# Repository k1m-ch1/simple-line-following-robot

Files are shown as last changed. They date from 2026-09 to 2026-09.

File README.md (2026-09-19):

So we want our angle at which the ir sensor still detect the line to be around 45 to 60 degrees.

So if the distance from the furthest sensor to the middle is $x$, and the distance between the "axel line" and the sensor itself is $r$, then:

$$
\tan \theta = \frac{x}{r}
$$

So, if we actual heading in PID (not very accurate, but I think it's a good mapping):

$$
\theta = \arctan {\frac{x}{r}}
$$

In our case:

- $x \approx 27.5mm$

For $\theta = 60$:

$$
r = \frac{x}{\tan\theta} = \frac{27.5}{\tan 60} = 15.9mm
$$

For $\theta = 30$ meanwhile:

$$
r = 47.63mm
$$

# Microcontroller

I'll try to use the stm32 blue pill for this project because it's high in abundance in terms of I/O. The downside though is that it requires an st-link, and uploading requires like messing around with the jumpers.

I'll see whether using platform io will make this process a bit easier.

Pins:

```
PA0  ADC1_IN0
PA1  ADC1_IN1
PA2  ADC1_IN2
PA3  ADC1_IN3

PA4  ADC1_IN4
PA5  ADC1_IN5
PA6  ADC1_IN6
PA7  ADC1_IN7

PB0  ADC1_IN8
PB1  ADC1_IN9

PC0  ADC1_IN10
PC1  ADC1_IN11
PC2  ADC1_IN12
PC3  ADC1_IN13
PC4  ADC1_IN14
PC5  ADC1_IN15
```

So these all support ADC, meaning that we can have like 2 of these 8 way line sensors!

Anyway, in the platformio world, we can just use `analogRead` for ADC. It's just that it's going to be 12 bits now, which is pretty neat.

## UART

So on the board, A is going to refer to PORT A probably.

### UART 1

```
PA9  → TX
PA10 → RX
```

### UART 2

```
PA2 → TX
PA3 → RX
```

### UART 3

```
PB10 → TX
PB11 → RX
```

## SPI

### SPI 1

```
PA5 → SCK
PA6 → MISO
PA7 → MOSI
```

### SPI 2

```
PB13 → SCK
PB14 → MISO
PB15 → MOSI
```

## I2C

```
PB6 → SCL
PB7 → SDA
```

# Safe GPIO

Safe:

```
PA0–PA7
PB0–PB1
PB5–PB9
PC0–PC15
```

Don't use:

```
PA13 → SWDIO
PA14 → SWCLK
```

## Interrupts

External interrupts are defined like this:

| EXTI line  | Possible GPIO pins |
| --- | --- |
| **EXTI0**  | PA0, PB0, PC0, ... |
| **EXTI1**  | PA1, PB1, PC1, ... |
| **EXTI2**  | PA2, PB2, PC2, ... |
| **EXTI3**  | PA3, PB3, PC3, ... |
| **EXTI4**  | PA4, PB4, PC4, ... |
| **EXTI5**  | PA5, PB5, PC5, ... |
| **EXTI6**  | PA6, PB6, PC6, ... |
| **EXTI7**  | PA7, PB7, PC7, ... |
| **EXTI8**  | PA8, PB8, PC8, ... |
| **EXTI9**  | PA9, PB9, PC9, ... |
| **EXTI10** | PA10, PB10, PC10, ... |
| **EXTI11** | PA11, PB11, PC11, ... |
| **EXTI12** | PA12, PB12, PC12, ... |
| **EXTI13** | PA13, PB13, PC13, ... |
| **EXTI14** | PA14, PB14, PC14, ... |
| **EXTI15** | PA15, PB15, PC15, ... |

So basically, if PA0 uses external interrupts, then PB0, PC0,.. can't use it.

## PWM and bluepill max resolution

Seems like: `16-bit` has a max frequency of `1098.6 Hz`, so the frequency is definitely high enough Servos and even motor control (Arduino's `analogWrite` is also around 1KHz, or even less than that).

Maximum resolution is:

```
b = \log_2 (\frac{f_{timer}}{f_pwm}})
```

For DC motors, I guess a resolution of 10 bits at 20000 Hz should be fine.

## Timers

Timers are grouped as such:

| Timer | Channels | Typical pins |
| --- | --- | --- |
| **TIM1** | CH1–CH4  | PA8, PA9, PA10, PA11 |
| **TIM2** | CH1–CH4  | PA0, PA1, PA2, PA3 |
| **TIM3** | CH1–CH4  | PA6, PA7, PB0, PB1 |
| **TIM4** | CH1–CH4  | PB6, PB7, PB8, PB9 |

timers should also be mapped as such:

| Pin | Possible timer channel |
| --- | --- |
| PA0 | TIM2_CH1 |
| PA1 | TIM2_CH2 |
| PA2 | TIM2_CH3 |
| PA3 | TIM2_CH4 |
| PA6 | TIM3_CH1 |
| PA7 | TIM3_CH2 |
| PB0 | TIM3_CH3 |
| PB1 | TIM3_CH4 |
| PB6 | TIM4_CH1 |
| PB7 | TIM4_CH2 |
| PB8 | TIM4_CH3 |
| PB9 | TIM4_CH4 |

So this code works:

```c
#include <Arduino.h>

#define FREQ_SERVO 50
#define DUTY_CYCLE_SERVO 0.5f

#define FREQ_MOTOR 20000
#define DUTY_CYCLE_MOTOR 0.5f

#define SERVO_PIN PA0

#define MOTOR_PIN PB7

// PB7 | TIM4_CH2               |

HardwareTimer timerServo(TIM2);
HardwareTimer timerMotor(TIM4);

void setup() {
  timerServo.setPWM(1,                     // TIM2 channel 1
                    SERVO_PIN,             // pin
                    FREQ_SERVO,            // frequency
                    DUTY_CYCLE_SERVO * 100 // duty %
  );
  timerServo.resume();

  timerMotor.setPWM(2, MOTOR_PIN, FREQ_MOTOR, DUTY_CYCLE_MOTOR * 100);

  timerMotor.resume();
}

void loop() {}
```

# Servo control

We're not using servos, but it would be nice to know how you would control it very precisely.

First of all, we have angle $\alpha$, then we have the frequency $f$. We want the "ON" pulse to be in the range between $t_{min}$ to $t_{max}$ for the full range.

So essentially, our time period $T$ is going to be $T = \frac{1}{f}$. Then our duty cyle $d = \frac{t}{T}$. Finally, if our angle is 0 to 180, we map it as such:

$$
d = \frac{t_{min} + alpha * \frac{t_{max} - t_{min}}{180}}
$$

Or a another interpretation is a linear blend:

$$
d = f * ((1 - \frac{alpha}{180})t_{min} + \frac{\alpha}{180}t_{max})
$$

We choose $t_{min} = 0.5 ms$ and $t_{max} = 2.5 ms$ for the full range.

So basically, we're blending between $0.5 \times 10^{-3} \times 50 = 0.025$ and $1.5 \times 10^{-3} \times 50 = 0.125$ in terms of duty cycle.

# Timers

So the issue with using the `HardwareTimer` API is that it does have some mechanisms for specifying the PWM signal using parameters such as frequency and duty cycle. The issue is that it rounds off our duty cycle parameter to the nearest integer percentage, which isn't good.

So what we're going to do is reinvent some sort of wheel, and build a PWM abstraction layer similar to the ledc hardware on the ESP32 chip, although we won't manually specify the PWM's resolution, rather, given a duty cycle, we will maximize our resolution every time.

I'll just write it in `pwm.h`, and i'll just call it `pwmAttach` to configure the frequency and `pwmWrite` to set the duty cycle.

Essentially, timers on the STM32 (and probably similarly for the Arduino) works as follows:

> [!NOTE]
> We're assuming that we're assuming that we're using PWM1 mode

- we have a base clock that runs at a fixed frequency $f_b$
- we have a prescale value which is an integer, that just basically says, after this many ticks of the base clock, increment the counter. We'll call this $p$, and on the STM32 $p = PSC + 1$
- we then have the counter overflow value, which in our case, we'll call $q$, which says, how many values do you want some counter to increment, until it overflows. In the STM32, this is $q = ARR + 1$. This determines the frequency of our PWM signal

So at this stage, we essentially have a counter that counts like: 0, 1, 2,..., q - 1, 0, 1, ..., q - 1. To get a PWM signal, we want to specify the duty cycle, which just says every period, what's the "on period percentage"?

- To get this, we essentially require a cutoff count $c$, such that $d = \frac{c}{q}$, an perhaps tweaked a bit depending on what we're actually doing. It's probably the case that for $\leq c$, it should go high, and $\geq c$, it should go low. On the stm32, $c = CCR$?

> [!NOTE]
> on the STM32, some pins uses the same timers, and each pin would then have a seperate channel, meaning that they use the same ARR, but different CCR. That's to say, they have the same frequency, but can have different duty cycles.

Also, it seems like we can't just arbitrarily set the prescale value to 1, because, if we want low frequency, then the ARR register might overflow, as such, it's best to set the prescale value to something lower. So more degrees of freedom you have to deal with...

# Pin definitions

For convenience, I will just connect PA0, PA1, PA2, ..., PA7 to the output of the 8 way IR sensor.

The IR pin can be connected to like PB0. And the 5V and ground will be connected respectively.

I'll also need to place some sort of 5V regulator, or maybe just a simple external 3.3V battery or something is probably fine. Or maybe an external powerbank for now, although, it would be best if we used a 5V regulator to one battery.

I guess we can use PB1 or something for PWM also, although, PB0 and PB1 would be using the same timer. This is fine though, because, since we can vary the duty cycle, this is fine.

As for controlling the motor directions, I guess we can use PB3, PB4, PB6, and PB7. And I guess that's it. We can still access PB10 and PB11 for the Serial3 port.

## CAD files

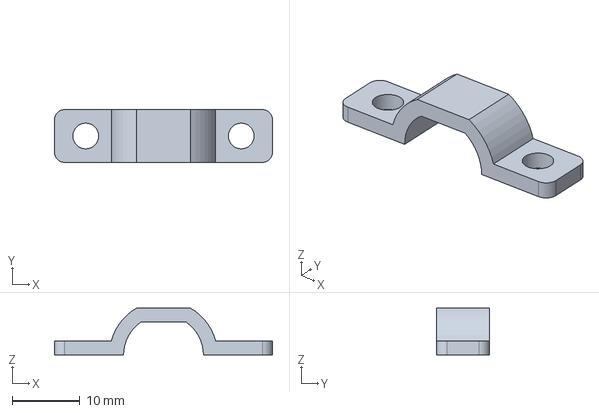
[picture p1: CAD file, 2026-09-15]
models/line_following_robot_v2.FCStd
32.2 x 7.80 x 6.95 mm

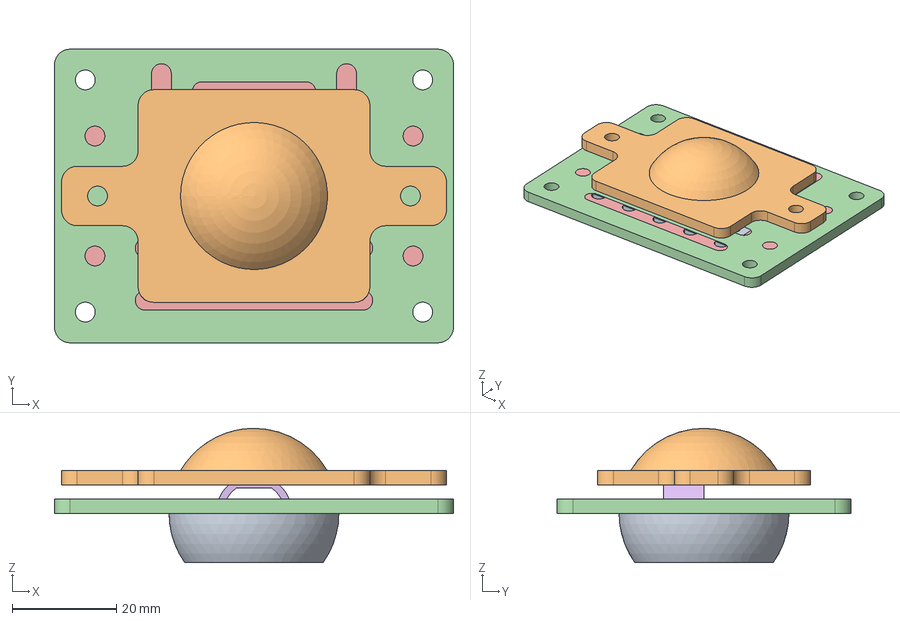
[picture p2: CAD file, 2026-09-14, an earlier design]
models/line_following_robot.FCStd
76.5 x 56.3 x 25.8 mm
spherical wheel base
spherical wheel cap
short_extenders
robot_base
robot_top_base
motor mount

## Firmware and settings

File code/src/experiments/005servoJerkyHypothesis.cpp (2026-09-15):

#include <Arduino.h>

#define SERVO_PIN PA0
#define FREQ_SERVO 50

#define DUTY_MIN 2.5f
#define DUTY_MAX 12.5f

#define SWEEP_TIME_MS 5000
#define STEPS 1000

HardwareTimer timerServo(TIM2);

void setup() {
  timerServo.setPWM(1, SERVO_PIN, FREQ_SERVO, DUTY_MIN);
  timerServo.resume();
}

void loop() {
  for (int i = 0; i <= STEPS; i++) {
    float t = i / (float)STEPS;

    float duty = DUTY_MIN + t * (DUTY_MAX - DUTY_MIN);

    timerServo.setPWM(1, SERVO_PIN, FREQ_SERVO, duty);

    delay(SWEEP_TIME_MS / STEPS);
  }

  for (int i = STEPS; i >= 0; i--) {
    float t = i / (float)STEPS;

    float duty = DUTY_MIN + t * (DUTY_MAX - DUTY_MIN);

    timerServo.setPWM(1, SERVO_PIN, FREQ_SERVO, duty);

    delay(SWEEP_TIME_MS / STEPS);
  }
}

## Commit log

2026-09-14 added initial model
    [line_following_robot.FCStd]
2026-09-15 tested stm32
2026-09-15 removed .pio from repository
    [line_following_robot_v2.FCStd]
2026-09-15 added some sort of timer and tested it
2026-09-16 made sense of timers
2026-10-11 added sensor definition
2026-10-11 got ir sensor working kinda reliably
2026-10-11 tested motors
